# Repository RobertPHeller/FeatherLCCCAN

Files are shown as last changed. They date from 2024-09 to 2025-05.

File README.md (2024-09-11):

# FeatherLCCCAN

This is a Feather Wing for ESP32 Feathers that contain a CAN tranceiver and 
RJ45 connectors that allow connecting an ESP32 Feather to a LCC network.  The
CAN is set up to use pin 11 for CAN_TX and pin 12 for CAN_RX.

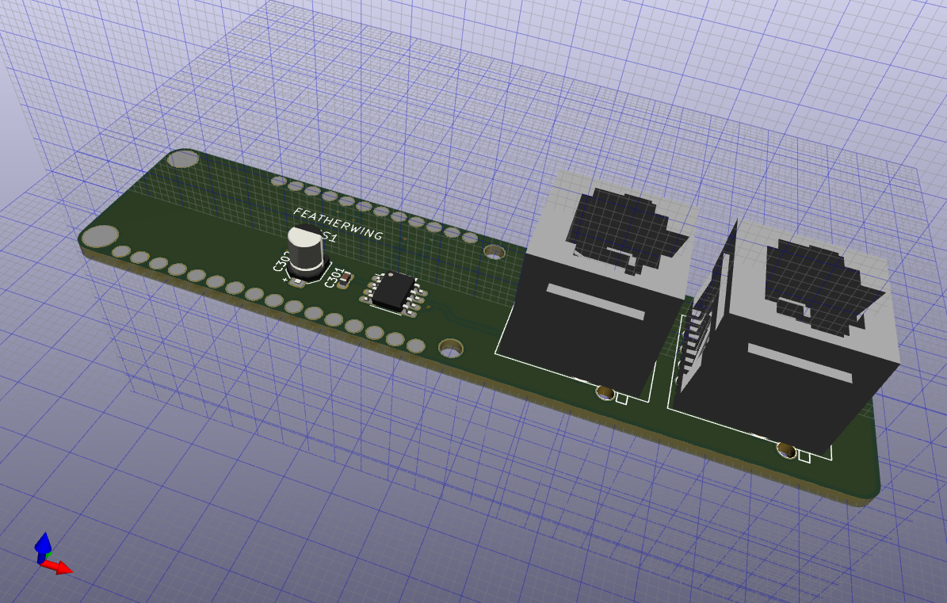
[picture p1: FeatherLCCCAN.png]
FeatherLCCCAN


Subdirectories:

- firmware Simple node, without the display, 4Meg partition table, stores node
  DB on Flash under SPIFFS
- firmware-display Complex node, with display, 8Meg partition table, stores 
  node DB on uSD card (assumes Adafruit 3.5" TFT w/Touch Screen V2.0, which
  includes a uSD card slot).
- DisplayCase FreeCAD code for a case for the version with display.

The firmware compiles with Espressif esp-idf (at least V 5.0) and uses Mike 
Dunston's OpenMRNIDF library.

I am using KiCAD 6.0.11 on a Raspberry Pi 5 running Debian 12.  Also I am using
FreeCAD .21.2 (aarch64 Appimage).

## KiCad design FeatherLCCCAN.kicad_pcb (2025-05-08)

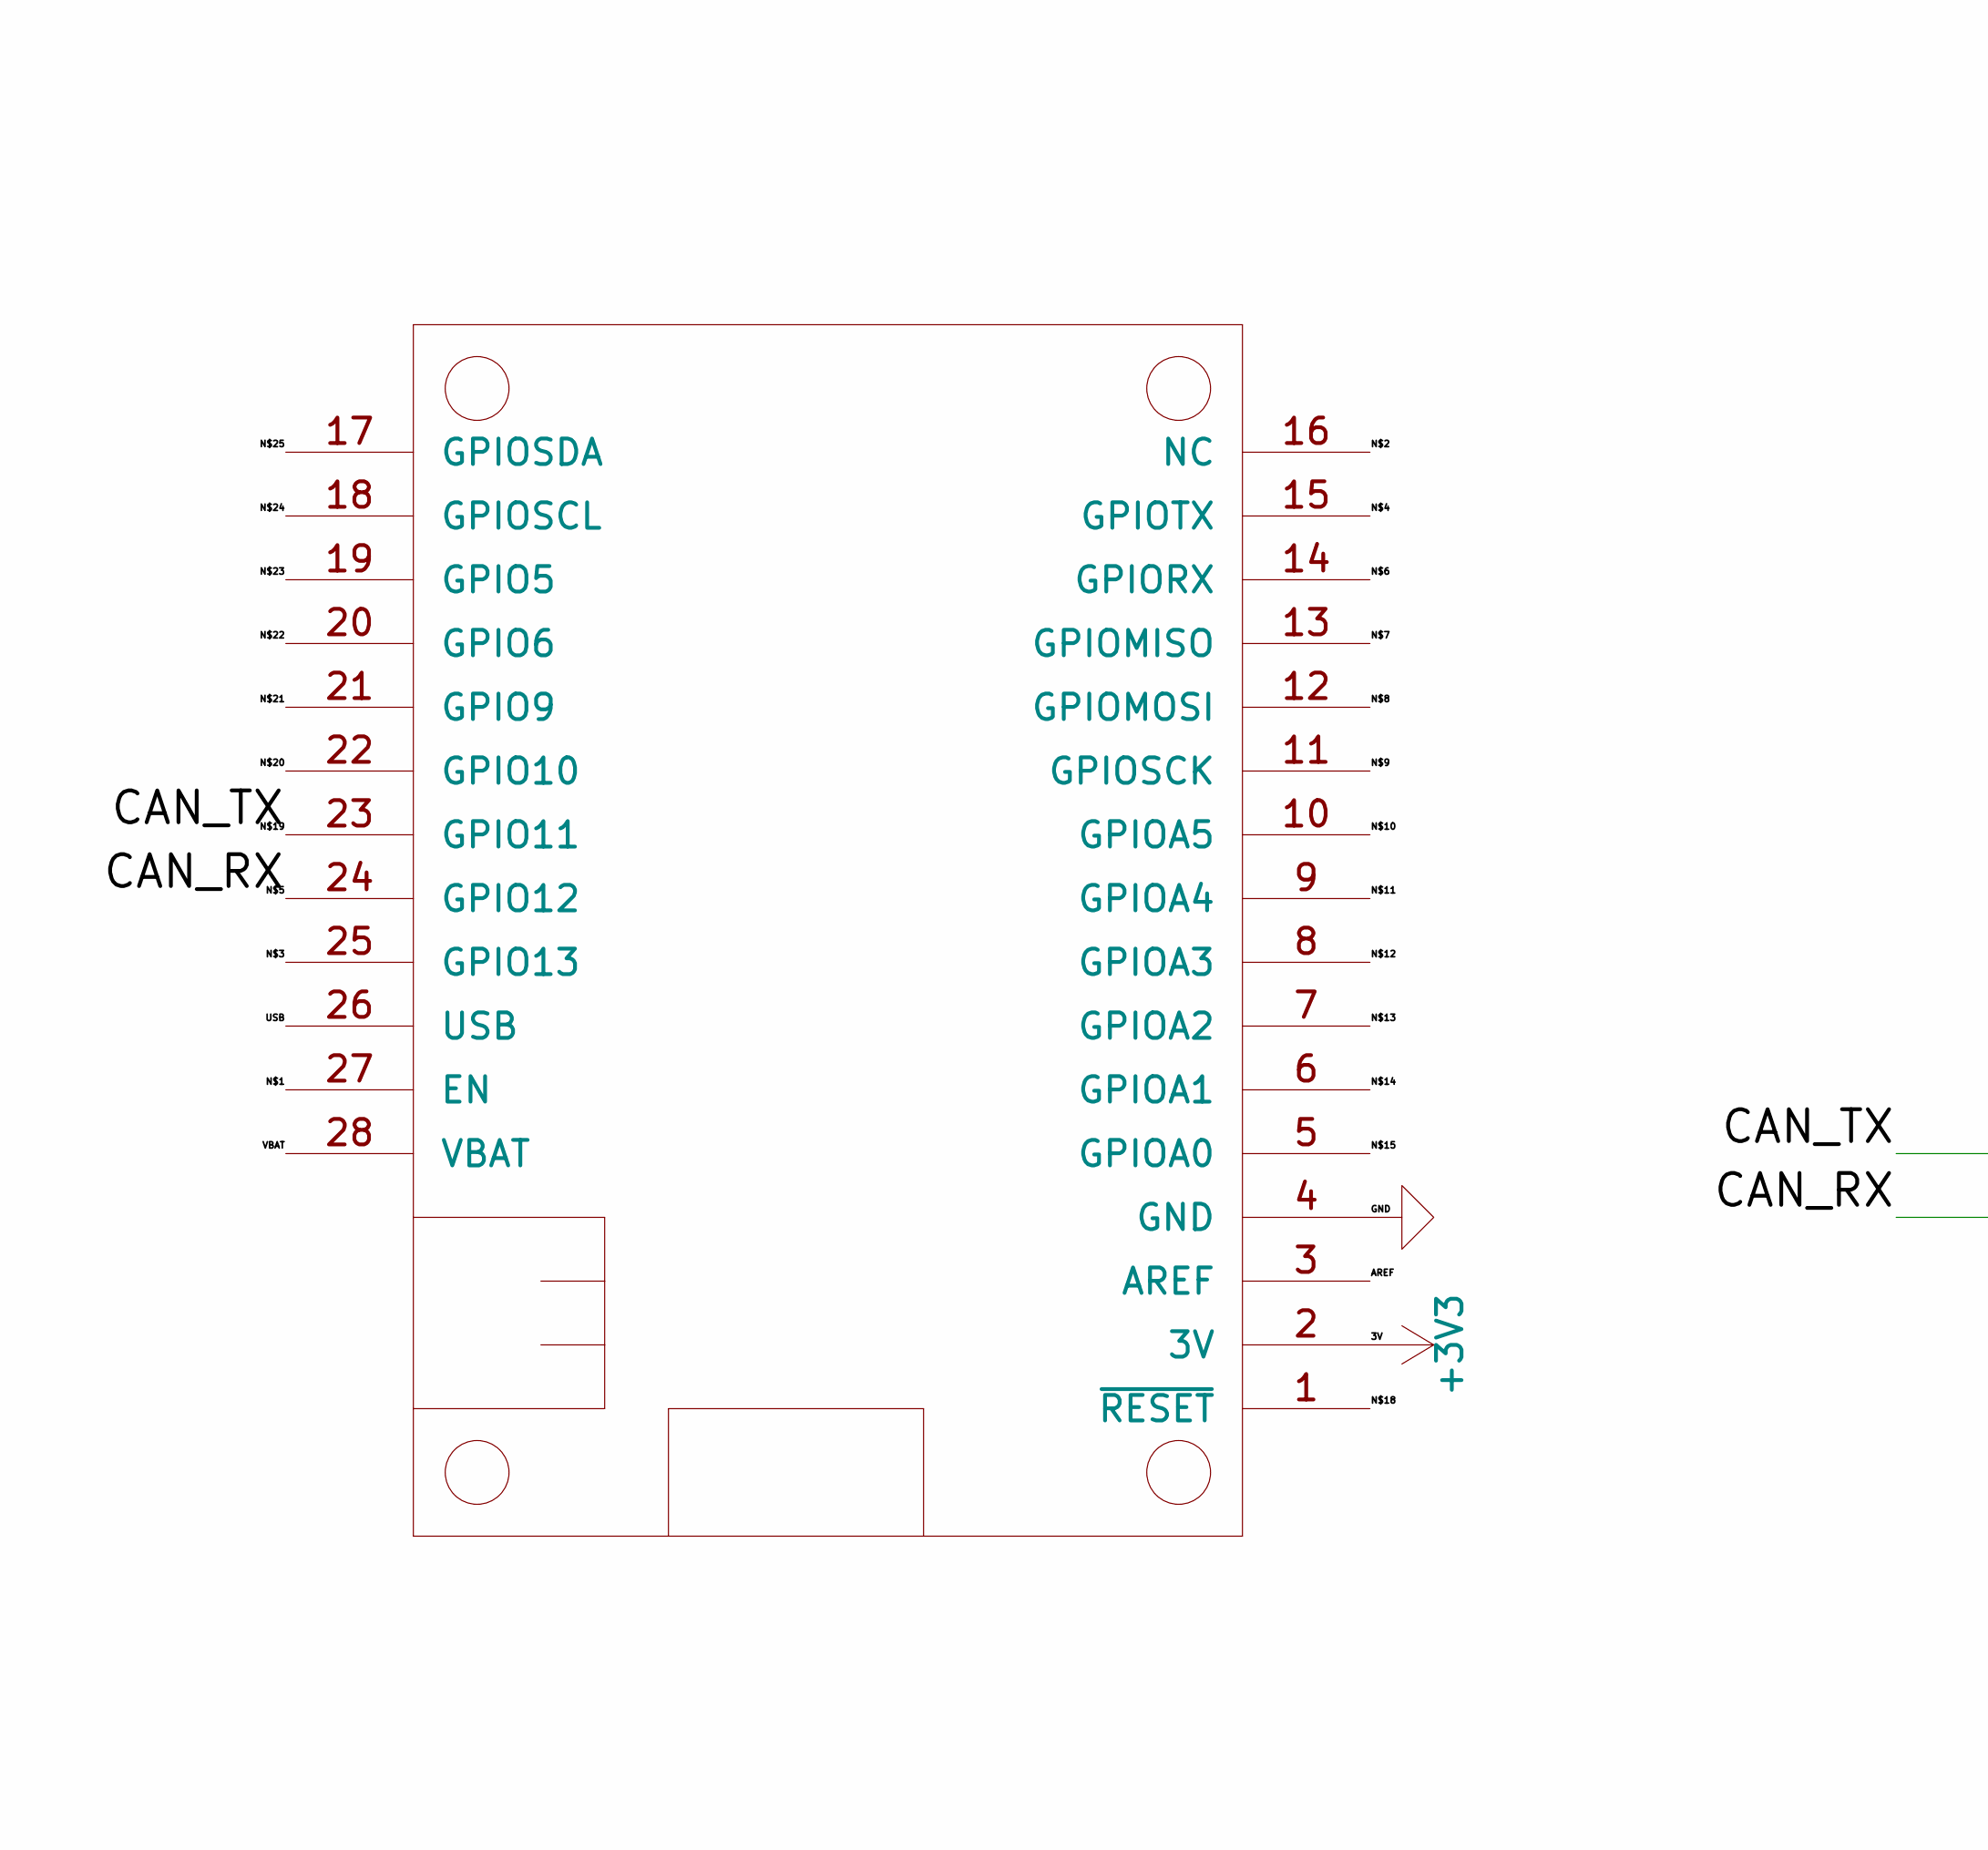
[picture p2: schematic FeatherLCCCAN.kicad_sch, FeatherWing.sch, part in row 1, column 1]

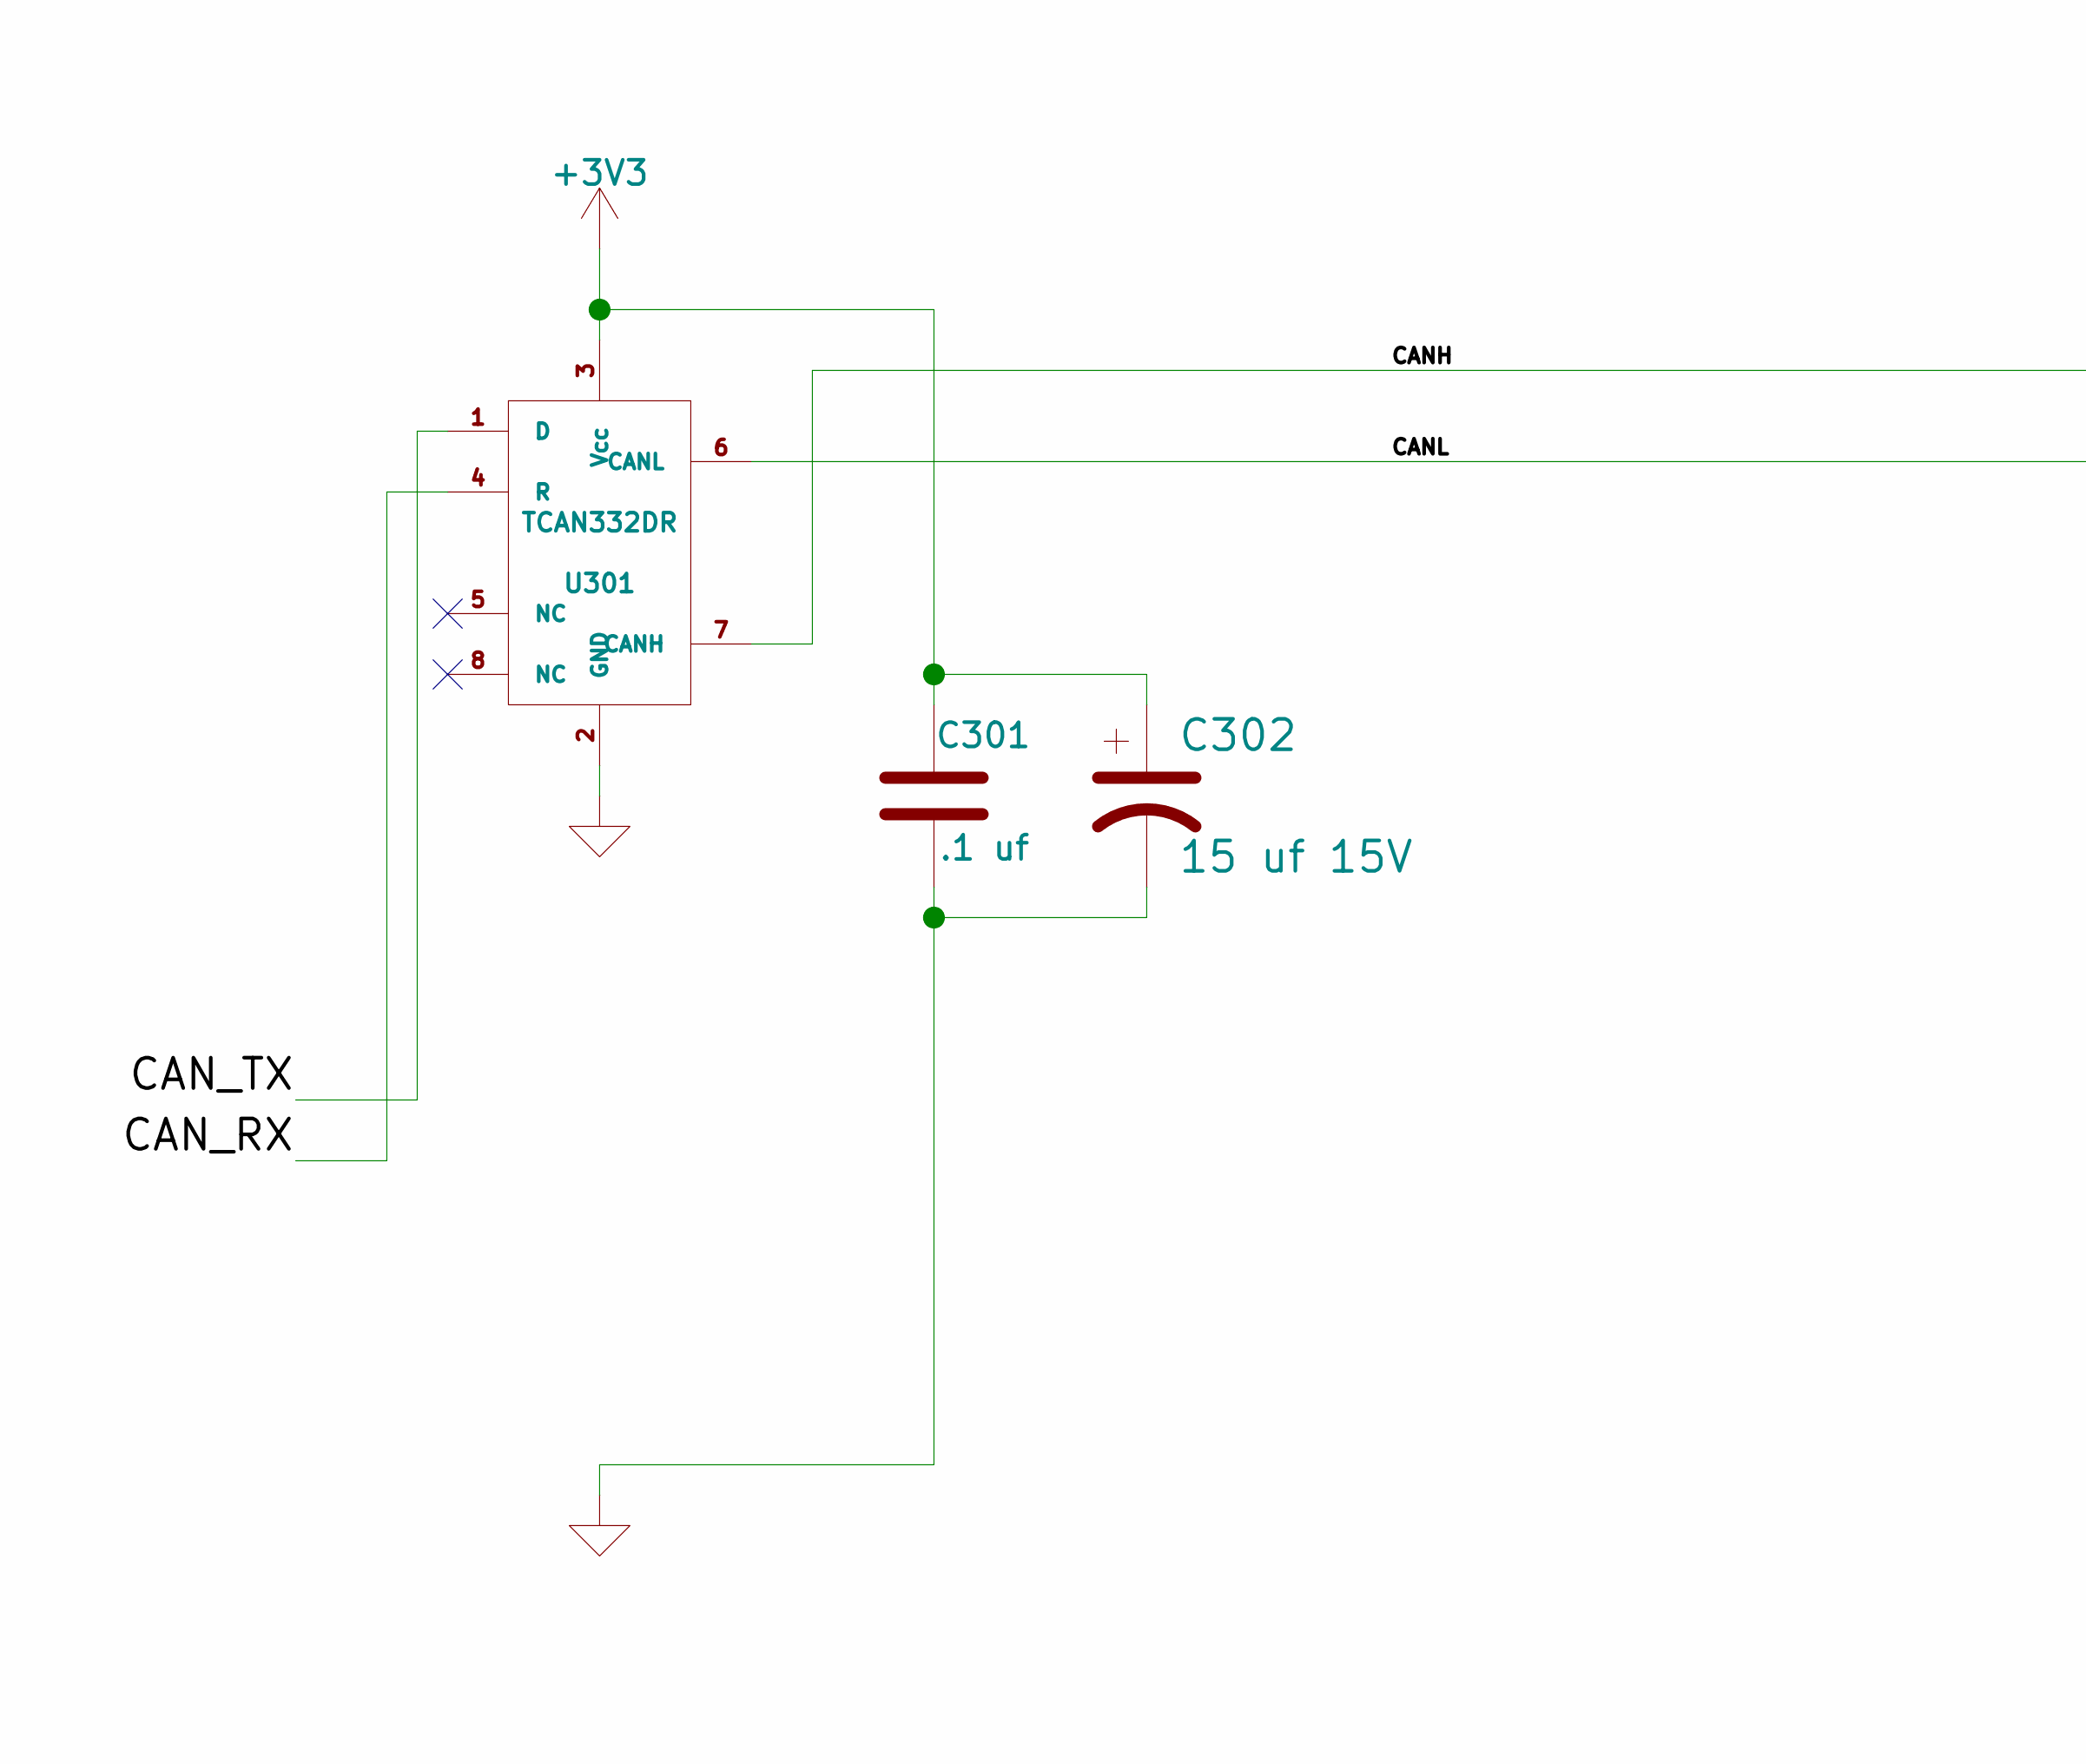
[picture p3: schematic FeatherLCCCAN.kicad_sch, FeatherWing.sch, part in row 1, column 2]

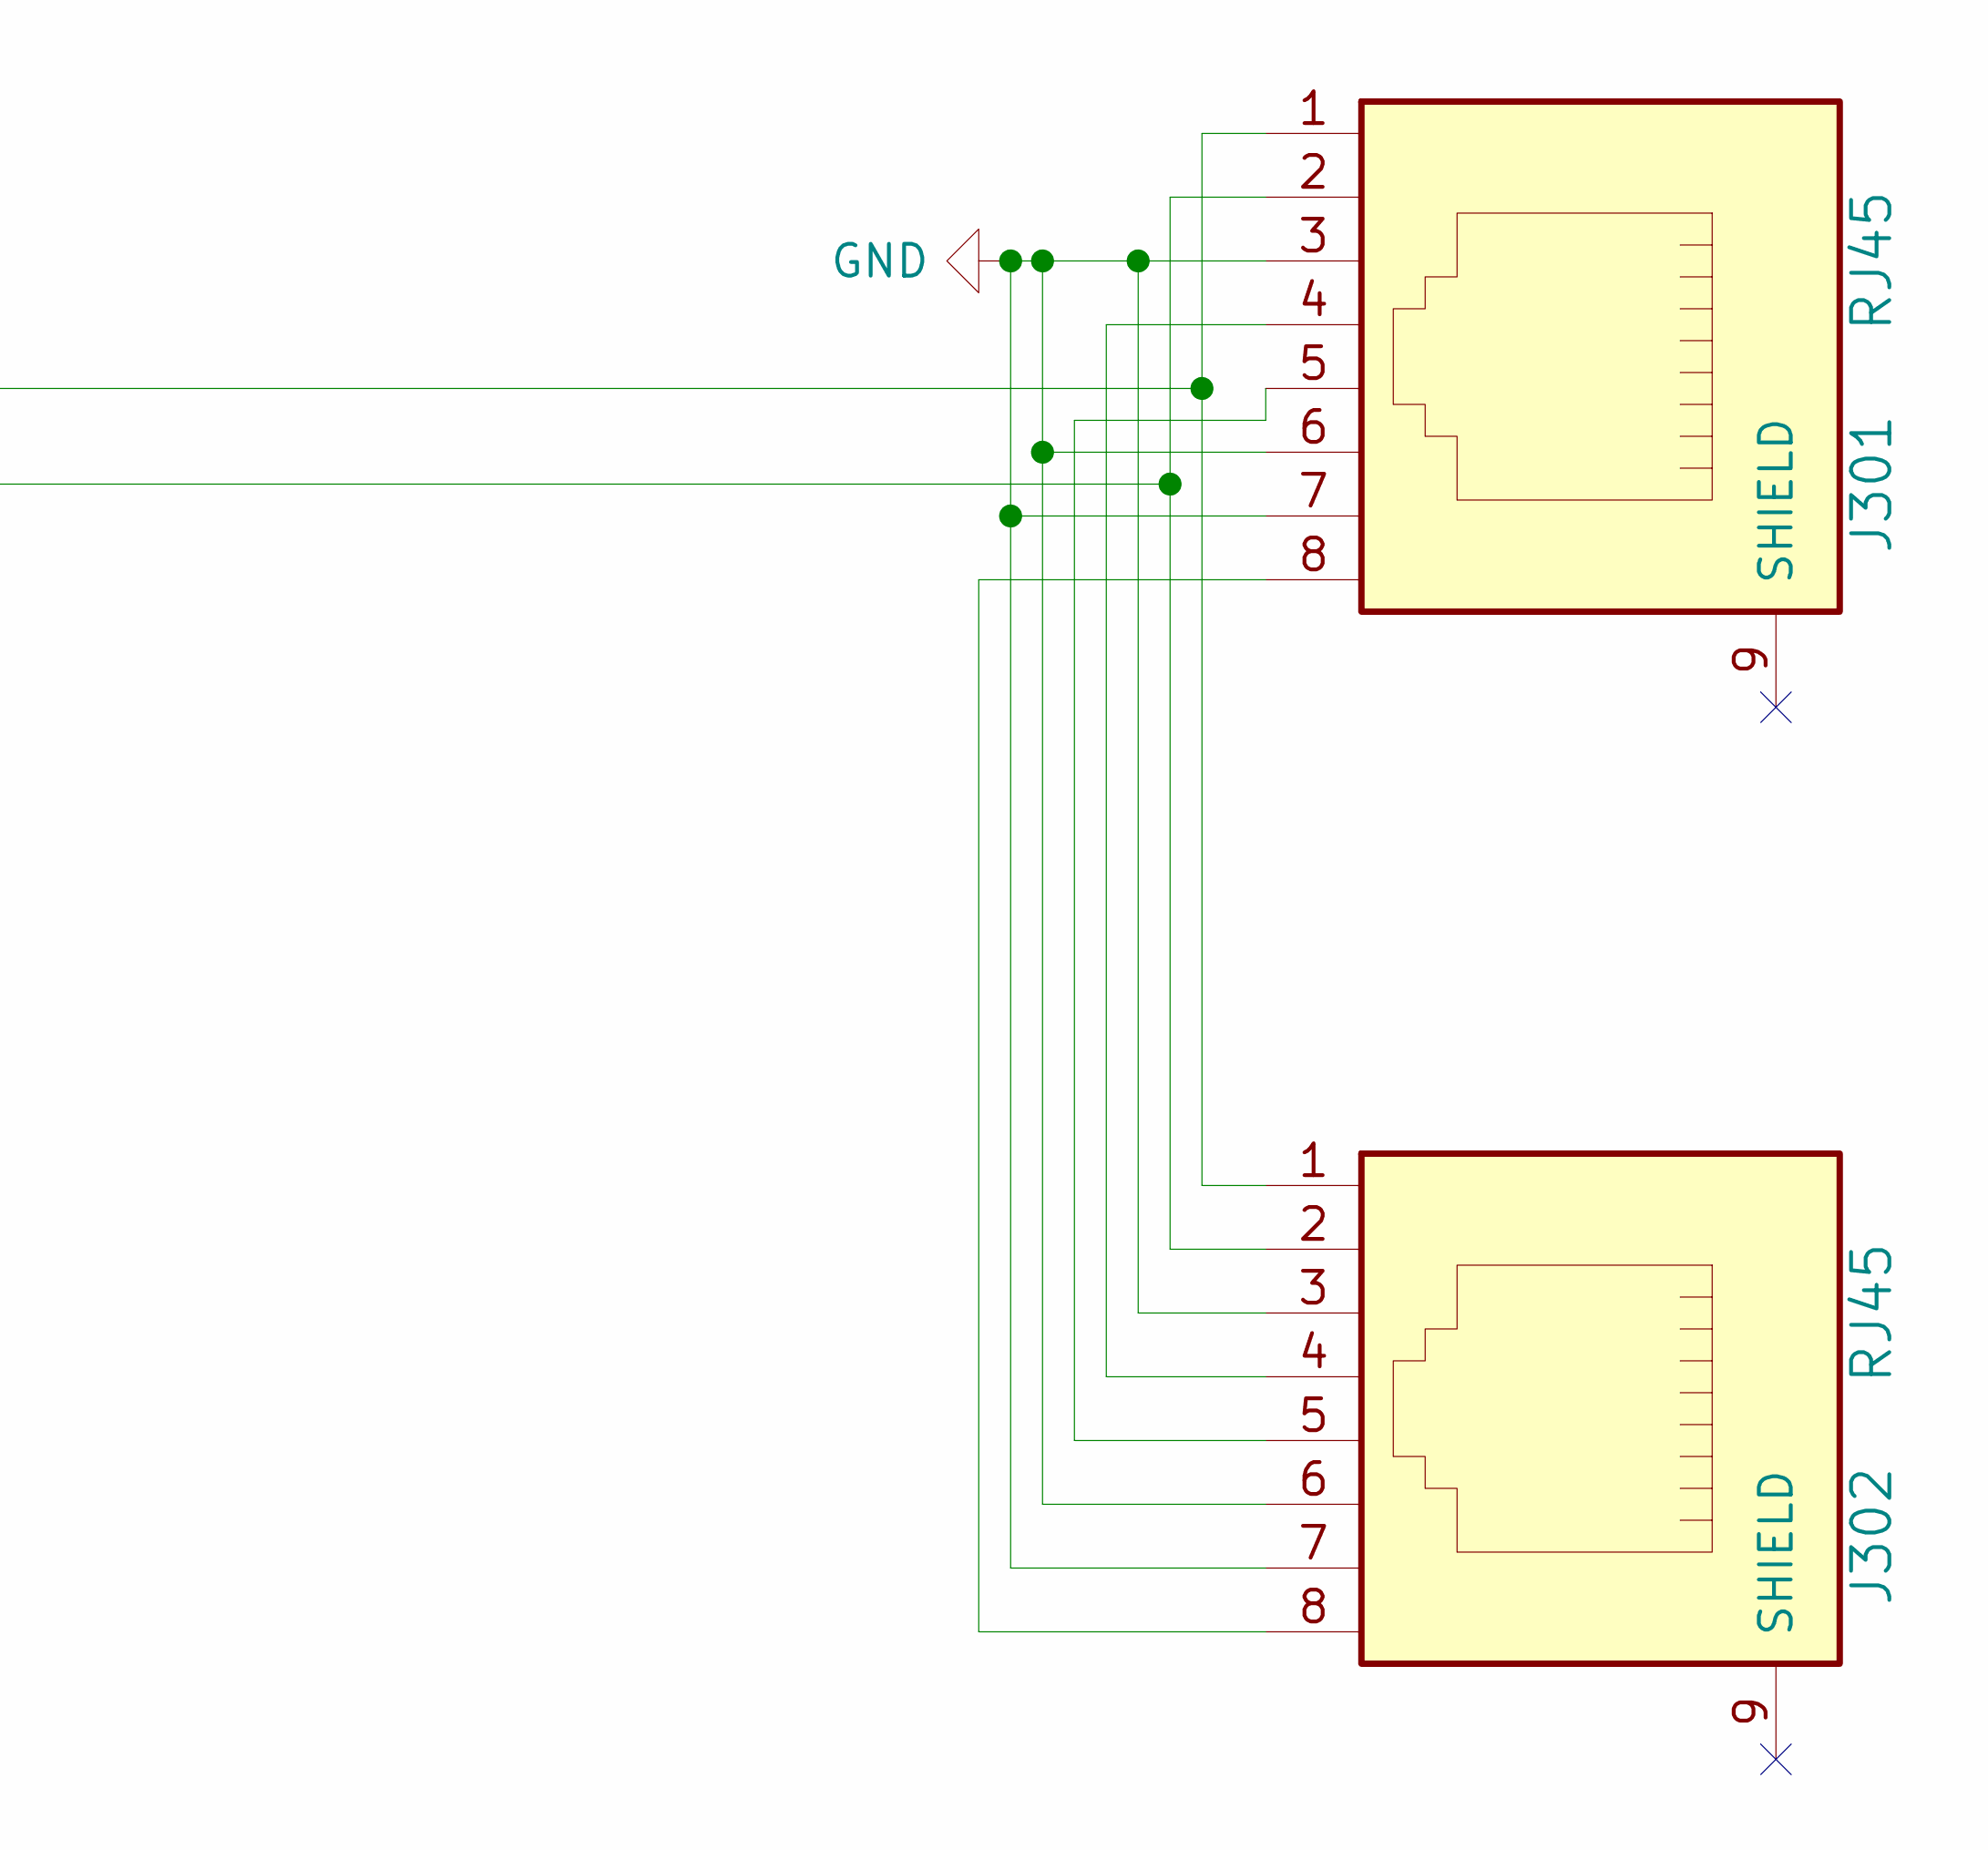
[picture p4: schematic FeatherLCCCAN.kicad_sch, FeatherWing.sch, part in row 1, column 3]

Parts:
C301: .1 uf; C_0603_1608Metric; Mouser Part Number 710-885012206095
C302: 15 uf 15V; CP_Elec_4x5.7; Mouser Part Number 647-UUD1C150MCL
J301, J302: RJ45; RJ45_8N-S; Mouser Part Number 710-615008144221
MS1: FEATHERWING
U301: TCAN332DR; SOIC-8_3.9x4.9mm_P1.27mm; Mouser Part Number 595-TCAN332DR

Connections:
+3V3: C301.1, C302.1, MS1.2 (3V), U301.3 (Vcc)
/AREF: MS1.3 (AREF)
/CANH: J301.1, J302.1, U301.7 (CANH)
/CANL: J301.2, J302.2, U301.6 (CANL)
/CAN_RX: MS1.24 (GPIO12), U301.4 (R)
/CAN_TX: MS1.23 (GPIO11), U301.1 (D)
/N$1: MS1.27 (EN)
/N$2: MS1.16 (NC)
/N$3: MS1.25 (GPIO13)
/N$4: MS1.15 (GPIOTX)
/N$6: MS1.14 (GPIORX)
/N$7: MS1.13 (GPIOMISO)
/N$8: MS1.12 (GPIOMOSI)
/N$9: MS1.11 (GPIOSCK)
/N$10: MS1.10 (GPIOA5)
/N$11: MS1.9 (GPIOA4)
/N$12: MS1.8 (GPIOA3)
/N$13: MS1.7 (GPIOA2)
/N$14: MS1.6 (GPIOA1)
/N$15: MS1.5 (GPIOA0)
/N$18: MS1.1 (~RESET)
/N$20: MS1.22 (GPIO10)
/N$21: MS1.21 (GPIO9)
/N$22: MS1.20 (GPIO6)
/N$23: MS1.19 (GPIO5)
/N$24: MS1.18 (GPIOSCL)
/N$25: MS1.17 (GPIOSDA)
/USB: MS1.26 (USB)
/VBAT: MS1.28 (VBAT)
GND: C301.2, C302.2, J301.3, J301.6, J301.7, J302.3, J302.6, J302.7, MS1.4 (GND), U301.2 (GND)
unnamed: J301.4, J302.4
unnamed: J301.5, J302.5
unnamed: J301.8, J302.8

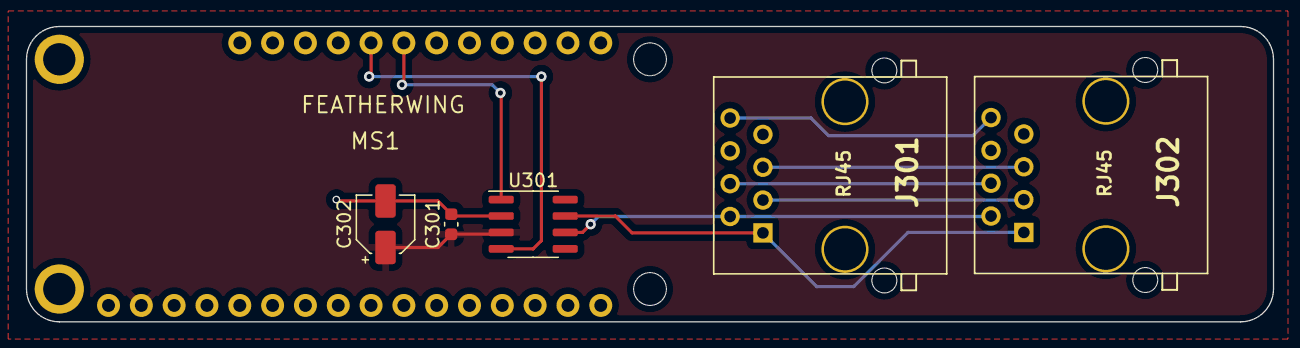
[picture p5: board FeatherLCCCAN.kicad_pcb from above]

Board: 2 copper layers, 96.5 x 22.9 mm, 6 parts (0 on the bottom side), 9 nets.

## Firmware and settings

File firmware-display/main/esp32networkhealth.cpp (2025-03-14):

// -!- C++ -!- //////////////////////////////////////////////////////////////
//
//  System        : 
//  Module        : 
//  Object Name   : $RCSfile$
//  Revision      : $Revision$
//  Date          : $Date$
//  Author        : $Author$
//  Created By    : Robert Heller
//  Created       : Tue Sep 3 22:18:49 2024
//  Last Modified : <250314.1708>
//
//  Description	
//
//  Notes
//
//  History
//	
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
static const char rcsid[] = "@(#) : $Id$";


#include "sdkconfig.h"
#include "cdi.hxx"
#include "cdidata.hxx"
#include "FactoryResetHelper.hxx"
#include "HealthMonitor.hxx"
#include "fs.hxx"
#include "hardware.hxx"
#include "NvsManager.hxx"
#include "NodeRebootHelper.hxx"
#include "BootPauseHelper.hxx"

#include <algorithm>
#include <driver/i2c.h>
#include <driver/uart.h>
#include <esp_err.h>
#include <esp_log.h>
#include <esp_ota_ops.h>
#include <esp_system.h>
#include <esp_task_wdt.h>
#include <freertos_includes.h>   
#include <openlcb/SimpleStack.hxx>
#include <freertos_drivers/esp32/Esp32HardwareTwai.hxx>
#include <freertos_drivers/esp32/Esp32WiFiManager.hxx>
#include <freertos_drivers/esp32/Esp32BootloaderHal.hxx>
#include <freertos_drivers/esp32/Esp32SocInfo.hxx>
#include <freertos_drivers/esp32/Esp32Ledc.hxx>
#include <openlcb/MemoryConfigClient.hxx>
#include <openlcb/RefreshLoop.hxx>
#include <openlcb/SimpleStack.hxx>
#include <utils/constants.hxx>
#include <utils/format_utils.hxx>

#include "Esp32SPI.hxx"
#include "Adafruit_HX8357.h"
#include "freertos_drivers/esp32/Esp32HardwareI2C.hxx"
#include "Adafruit_TSC2007.h"

#include "NetworkHealthScan.hxx"
#include "DisplayNetworkHealth.hxx"

///////////////////////////////////////////////////////////////////////////////
// Increase the CAN RX frame buffer size to reduce overruns when there is high
// traffic load (ie: large datagram transport).
///////////////////////////////////////////////////////////////////////////////
OVERRIDE_CONST(can_rx_buffer_size, 64);
OVERRIDE_CONST(num_memory_spaces, 8);

esp32networkhealth::ConfigDef cfg(0);
Esp32HardwareTwai twai(CONFIG_TWAI_RX_PIN, CONFIG_TWAI_TX_PIN);
Esp32SPI spibus;
Esp32SPI::SpiDevice *sdcard;
Adafruit_HX8357 display(CONFIG_DCS,DRs_Pin::instance(),nullptr);
Esp32HardwareI2C i2c("/dev/i2c");
Adafruit_TSC2007 touchscreen;

namespace openlcb
{

/// Name of CDI.xml to generate dynamically.
const char CDI_FILENAME[] = "/fs/cdi.xml";

// Path to where OpenMRN should persist general configuration data.
extern const char *const CONFIG_FILENAME = "/fs/config";

// The size of the memory space to export over the above device.
extern const size_t CONFIG_FILE_SIZE = cfg.seg().size() + cfg.seg().offset();

// Default to store the dynamic SNIP data is stored in the same persistant
// data file as general configuration data.
extern const char *const SNIP_DYNAMIC_FILENAME = "/fs/config";

/// Defines the identification information for the node. The arguments are:
///
/// - 4 (version info, always 4 by the standard
/// - Manufacturer name
/// - Model name
/// - Hardware version
/// - Software version
///
/// This data will be used for all purposes of the identification:
///
/// - the generated cdi.xml will include this data
/// - the Simple Node Ident Info Protocol will return this data
/// - the ACDI memory space will contain this data.
extern const SimpleNodeStaticValues SNIP_STATIC_DATA =
{
    4,
    SNIP_PROJECT_PAGE,
    SNIP_PROJECT_NAME,
    SNIP_HW_VERSION,
    SNIP_SW_VERSION
};

/// Modify this value every time the EEPROM needs to be cleared on the node
/// after an update.
static constexpr uint16_t CANONICAL_VERSION = CDI_VERSION;

} // namespace openlcb


extern "C"
{

void *node_reboot(void *arg)
{
    Singleton<reboothelpers::NodeRebootHelper>::instance()->reboot();
    return nullptr;
}

void reboot()
{
    os_thread_create(nullptr, nullptr, uxTaskPriorityGet(NULL) + 1, 2048
                     , node_reboot, nullptr);
}
ssize_t os_get_free_heap()
{
    return heap_caps_get_free_size(MALLOC_CAP_8BIT);
}


namespace esp32networkhealth {


ConfigUpdateListener::UpdateAction FactoryResetHelper::apply_configuration(
                                                                           int fd, bool initial_load, BarrierNotifiable *done)
{
    // nothing to do here as we do not load config
    AutoNotify n(done);
    LOG(VERBOSE, "[CFG] apply_configuration(%d, %d)", fd, initial_load);
    if (!initial_load &&
        Singleton<nvsmanager::NvsManager>::instance()->CheckPersist())
    {
        LOG(WARNING, "[CFG] NVS has been updated requesting a restart.");
        return ConfigUpdateListener::UpdateAction::REBOOT_NEEDED;
    }
    
    return ConfigUpdateListener::UpdateAction::UPDATED;
}

void FactoryResetHelper::factory_reset(int fd)
{
    LOG(VERBOSE, "[CFG] factory_reset(%d)", fd);
    // set the name of the node to the SNIP model name
    cfg.userinfo().name().write(fd, openlcb::SNIP_STATIC_DATA.model_name);
    cfg.userinfo().description().write(fd, "");
    
}

}

void app_main()
{
    // capture the reason for the CPU reset
    uint8_t reset_reason = Esp32SocInfo::print_soc_info();
    
    LOG(INFO, "[SNIP] version:%d, manufacturer:%s, model:%s, hw-v:%s, sw-v:%s"
        , openlcb::SNIP_STATIC_DATA.version
        , openlcb::SNIP_STATIC_DATA.manufacturer_name
        , openlcb::SNIP_STATIC_DATA.model_name
        , openlcb::SNIP_STATIC_DATA.hardware_version
        , openlcb::SNIP_STATIC_DATA.software_version);
    bool reset_events = false;
    bool cleanup_config_tree = false;
    
    GpioInit::hw_init();
    spibus.hw_initbus(CONFIG_MOSI,CONFIG_MISO,CONFIG_SCLK);
    display.begin(&spibus);
    i2c.hw_init(CONFIG_SDA_PIN,CONFIG_SDL_PIN, 100000);
    touchscreen.begin();
    sdcard = spibus.mount_sd_card("/sdcard",CONFIG_CardCS);
    
    nvsmanager::NvsManager nvs;
    nvs.init(reset_reason);
    
    LOG(INFO, "[BootPauseHelper] starting...");
    
    nvsmanager::BootPauseHelper pause;
    
    pause.CheckPause();
    LOG(INFO, "[BootPauseHelper] returned...");
    
    // Check for and reset factory reset flag.
    if (nvs.should_reset_config())
    {
        cleanup_config_tree = true;
        nvs.clear_factory_reset();
    }
    
    if (nvs.should_reset_events())
    {
        reset_events = true;
        // reset the flag so we start in normal operating mode next time.
        nvs.clear_reset_events();
    }
    nvs.CheckPersist();
    
    nvs.DisplayNvsConfiguration();
    mount_fs(cleanup_config_tree);
    openlcb::SimpleCanStack stack(nvs.node_id());
    LOG(INFO, "[MAIN] SimpleCanStack allocated");
#if CONFIG_OLCB_PRINT_ALL_PACKETS
    stack.print_all_packets();
#endif
    nvs.register_virtual_memory_spaces(&stack);
    openlcb::MemoryConfigClient memory_client(stack.node(), stack.memory_config_handler());
    LOG(INFO, "[MAIN] MemoryConfigClient allocated");
#ifdef CONFIG_ESP32_WIFI_ENABLED
    openmrn_arduino::Esp32WiFiManager wifi_manager(
                                                   nvs.station_ssid(), 
                                                   nvs.station_pass(),
                                                   &stack, 
                                                   cfg.seg().olbcwifi(), 
                                                   nvs.wifi_mode(),
                                                   (uint8_t)CONFIG_OLCB_WIFI_MODE, /* uplink / hub mode */
                                                   nvs.hostname_prefix());
#endif
    esp32networkhealth::FactoryResetHelper factory_reset_helper;
    LOG(INFO, "[MAIN] FactoryResetHelper allocated");
    healthmonitor::HealthMonitor health_mon(stack.service());
    LOG(INFO, "[MAIN] HealthMonitor allocated");
    NetworkHealthScan::NetworkHealthScan 
          healthScan(stack.node(),
                     stack.service(),
                     stack.executor()->active_timers(),
                     cfg.seg().scanConfig());
    openlcb::MemorySpace *space = healthScan.NodeDBSpace();
    stack.memory_config_handler()->registry()->insert(stack.node(),
                                                      CONFIG_NodeDB_SPACE,
                                                      space);
    DisplayNetworkHealth::DisplayNetworkHealth 
          displayNetHealth(&display,&touchscreen,&healthScan);
    openlcb::RefreshLoop loopdisplay(stack.node(),{&displayNetHealth});
    LOG(INFO, "[MAIN] config file size is %d",openlcb::CONFIG_FILE_SIZE);
    // Create config file and initiate factory reset if it doesn't exist or is
    // otherwise corrupted.
    int config_fd =
          stack.create_config_file_if_needed(cfg.seg().internal_config(),
                                             openlcb::CANONICAL_VERSION,
                                             openlcb::CONFIG_FILE_SIZE);
    stack.check_version_and_factory_reset(cfg.seg().internal_config(),
                                          CDI_VERSION,
                                          cleanup_config_tree);
    reboothelpers::NodeRebootHelper node_reboot_helper(&stack, config_fd);
    
    if (reset_events)
    {
        LOG(WARNING, "[CDI] Resetting event IDs");
        stack.factory_reset_all_events(cfg.seg().internal_config(), 
                                       nvs.node_id(), config_fd);
        fsync(config_fd);
    }
    
    
    // Initialize the TWAI driver.
    twai.hw_init();
    
    // Add the TWAI port to the stack.
    stack.add_can_port_select("/dev/twai/twai0");
    healthScan.ScanNetwork();
    // Start the stack in the background using it's own task.
    stack.loop_executor();
    // At this point the OpenMRN stack is running in it's own task and we can
    // safely exit from this one. We do not need to cleanup as that will be
    // handled automatically by ESP-IDF.
}



} // extern "C"

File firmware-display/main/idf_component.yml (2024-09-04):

dependencies:
  OpenMRNIDF:
    version: idf-v5
    git: https://github.com/atanisoft/OpenMRNIDF.git
  NVSManager:
    path: ../../../ESP32-LCC/CommonComponents/NVSManager
  FS:
    path: ../../../ESP32-LCC/CommonComponents/FS
  HealthMonitor:
    path: ../../../ESP32-LCC/CommonComponents/HealthMonitor
  RebootHelpers:
    path: ../../../ESP32-LCC/CommonComponents/RebootHelpers

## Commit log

2024-09-03 Completed LCC CAN Feather Wing.
    [FeatherLCCCAN.kicad_pcb, FeatherLCCCAN.kicad_sch]
2024-09-04 Build Infrastructure.
    [esp32networkhealth-partitions.csv]
2024-09-05 Change CAN pins (allow for Adafruit 3.5" FeatherWing TFT & TouchScreen).
    [FeatherLCCCAN.kicad_pcb, FeatherLCCCAN.kicad_sch]
2024-09-06 Starting on Display version of the firmware.
    [esp32networkhealth8meg-partitions.csv]
2024-09-06 Started on case.
2024-09-07 Add mounting and pin holes.
2024-09-07 Rev B PCB.
    [FeatherLCCCAN.kicad_pcb]
2024-09-07 Complete LCC CAN Wing and Feather.
2024-09-08 Finalize FeatherWing Display Board.
2024-09-09 Complete porting of Arduino-ish Adafruit code to OpenMRNIDF / FreeRTOS code.
2024-09-11 And STL export code.
2024-09-11 Add 3D view of the Rev B board.
2024-09-11 Add 3D models for the connectors and create 3D image.
    [FeatherLCCCAN.kicad_pcb]
2024-11-03 Build for a 4meg ESP32S3 Feather.
    [esp32networkhealth4meg-partitions.csv]
2025-01-21 Increase the stack sizes, update Makefile, add logging, prevent race condition.
    [NetworkHealthScan.cpp, esp32networkhealth.cpp]
2025-05-07 Update part numbers.
    [FeatherLCCCAN.kicad_pcb, FeatherLCCCAN.kicad_sch]
2025-05-08 Add MPN property (for PCBWay plugin).
    [FeatherLCCCAN.kicad_sch]

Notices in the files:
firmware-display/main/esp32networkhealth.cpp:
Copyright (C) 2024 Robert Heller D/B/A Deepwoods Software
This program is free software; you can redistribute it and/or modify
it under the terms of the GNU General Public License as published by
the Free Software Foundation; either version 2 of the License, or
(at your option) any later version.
